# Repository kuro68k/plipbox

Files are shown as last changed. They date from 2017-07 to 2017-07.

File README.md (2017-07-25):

# plipbox

PCB for lallafa's plipbox (http://lallafa.de/blog/amiga-projects/plipbox/).

Allows an Amiga to connect to an ethernet network via the parallel port. Very low cost, uses an Arduino Nano V3 and ethernet shield.

This PCB is 2 layers. There is no cost advantage to single layer when ordering from Chinese manufacturers like Seeed Studio, and two layers means no need for jumper wires.

In addition there is a low cost TTL to RS232 level shifter. It's entirely optional, and if fitted allows the Amiga to configure the plipbox via connection to the serial port.

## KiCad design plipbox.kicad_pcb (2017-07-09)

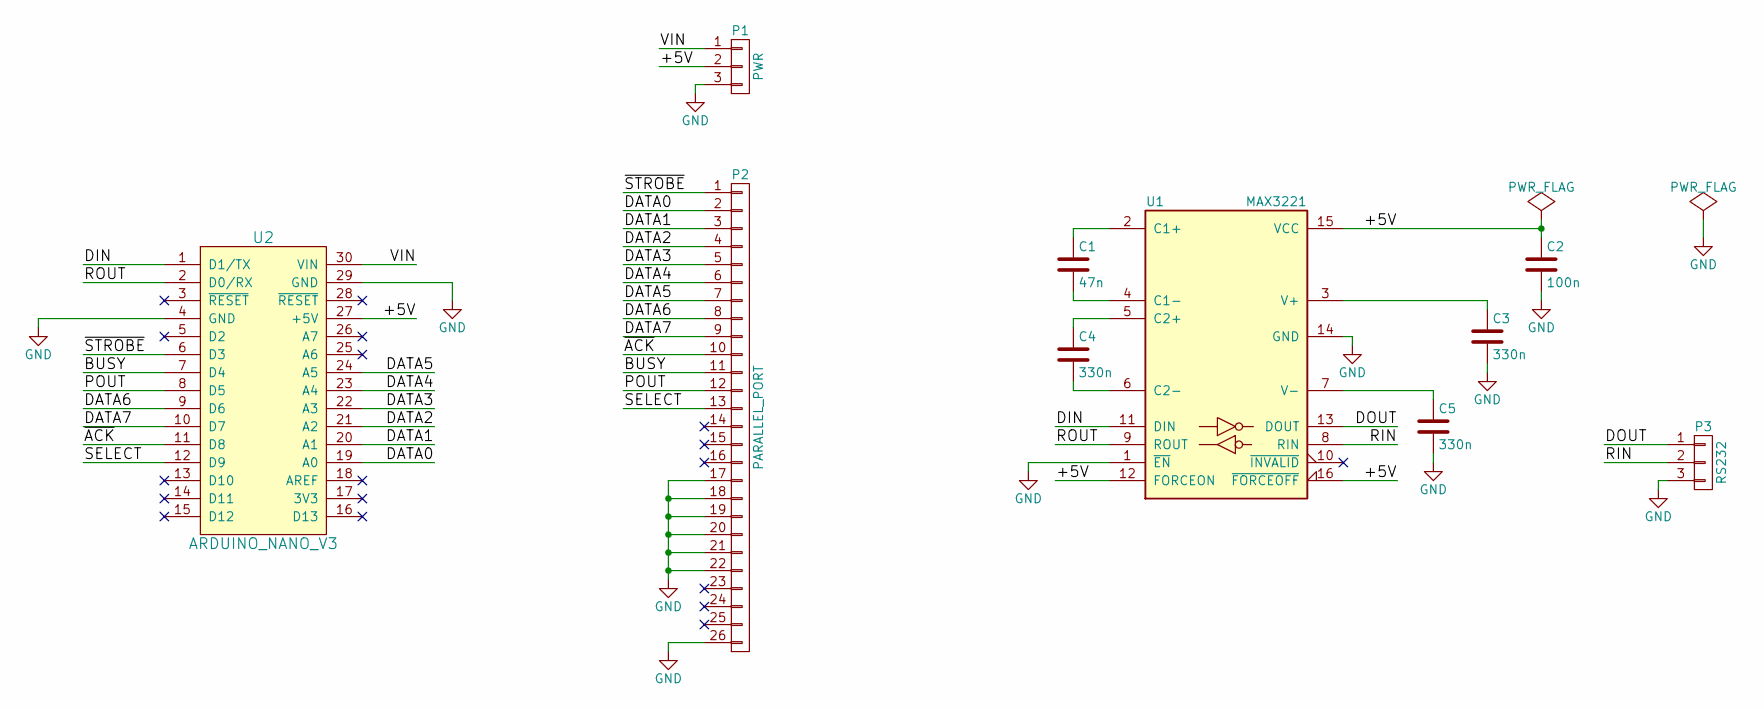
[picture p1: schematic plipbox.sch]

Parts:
C1: 47n; C_0603_HandSoldering
C2: 100n; C_0603_HandSoldering
C3, C4, C5: 330n; C_0603_HandSoldering
P1: PWR; Pin_Header_Straight_1x03_Pitch2.54mm
P2: PARALLEL_PORT; DB25M-RA-TH
P3: RS232; Pin_Header_Straight_1x03_Pitch2.54mm
U1: MAX3221; TSSOP-16_4.4x5mm_Pitch0.65mm
U2: ARDUINO_NANO_V3; DIP-30_W15.24mm_LongPads

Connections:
/+5V: C2.1, P1.2, U1.12 (FORCEON), U1.15 (VCC), U1.16 (~FORCEOFF), U2.27 (+5V)
/BUSY: P2.11, U2.7 (D4)
/DATA0: P2.2, U2.19 (A0)
/DATA1: P2.3, U2.20 (A1)
/DATA2: P2.4, U2.21 (A2)
/DATA3: P2.5, U2.22 (A3)
/DATA4: P2.6, U2.23 (A4)
/DATA5: P2.7, U2.24 (A5)
/DATA6: P2.8, U2.9 (D6)
/DATA7: P2.9, U2.10 (D7)
/DIN: U1.11 (DIN), U2.1 (D1/TX)
/DOUT: P3.1, U1.13 (DOUT)
/POUT: P2.12, U2.8 (D5)
/RIN: P3.2, U1.8 (RIN)
/ROUT: U1.9 (ROUT), U2.2 (D0/RX)
/SELECT: P2.13, U2.12 (D9)
/VIN: P1.1, U2.30 (VIN)
/~ACK: P2.10, U2.11 (D8)
/~STROBE: P2.1, U2.6 (D3)
GND: C2.2, C3.2, C5.2, P1.3, P2.17, P2.18, P2.19, P2.20, P2.21, P2.22, P2.26, P3.3, U1.1 (~EN), U1.14 (GND), U2.4 (GND), U2.29 (GND)
unnamed: C1.1, U1.2 (C1+)
unnamed: C1.2, U1.4 (C1-)
unnamed: C3.1, U1.3 (V+)
unnamed: C4.1, U1.5 (C2+)
unnamed: C4.2, U1.6 (C2-)
unnamed: C5.1, U1.7 (V-)

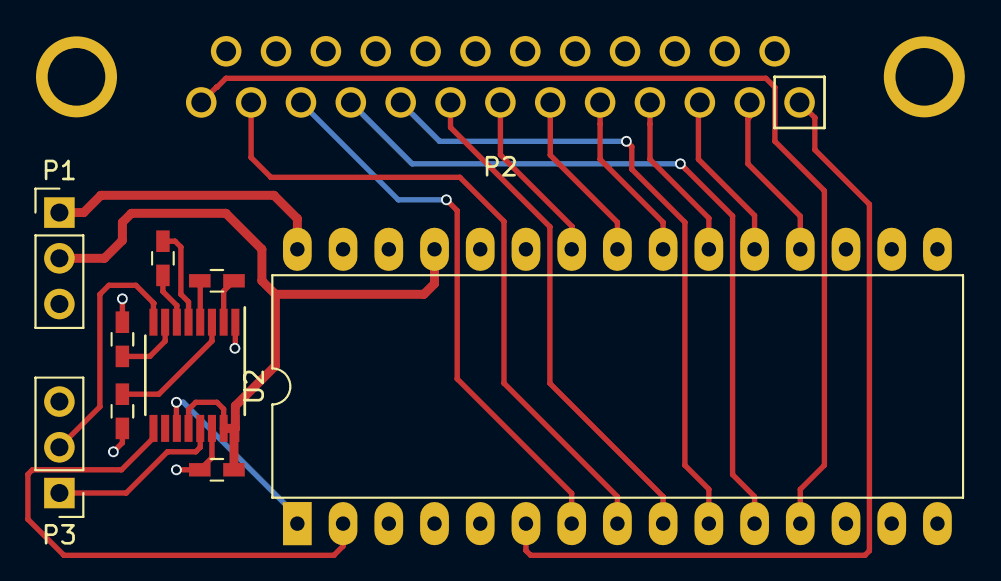
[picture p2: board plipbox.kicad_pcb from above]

Board: 2 copper layers, 10 parts (0 on the bottom side), 26 nets.

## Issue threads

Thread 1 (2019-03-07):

BOM / Parts list

soydemadrid, 2019-03-07:

sircompo, 2019-11-22:
Looking in the KiCad schematic (plipbox.sch), U1 appears to be a MAX3221 in a TSSOP-16 package.
https://www.ti.com/store/ti/en/p/product/?p=MAX3221IPWR

As for the caps, they're 0603 sized with the following values -
C1	47n
C2	100n
C3	330n
C4	330n
C5	330n

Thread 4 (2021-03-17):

RS232 Transceiver and Programming

appiah4, 2021-03-17:
Can you confirm the RS232 Transceiver BOM?  If U1 is indeed a MAX3221 (which is not easy to source) would SN35C3221EPWR work in its place?

Also, does the RS232 circuit connect directly to the Serial port?  What shell commands are needed to program it?  Can you add a bit more documentation.

kuro68k, 2021-03-17:
Is that part number right, Google comes up empty.

All documentation here: https://lallafa.de/blog/amiga-projects/plipbox/

appiah4, 2021-04-23:
Hi, I made a typo apparently, meant to ask about SN65C3321E PWR: https://cdn.ozdisan.com/ETicaret_Dosya/348021_4850776.pdf

Thanks for the link to the documentation.  I got a few boards printed and assembled one with the IC mentioned above.  Would it be safe to try?

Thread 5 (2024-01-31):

Hole sizes for DB25 and Nano different?

ByteMavericks, 2024-01-31:
Fitting the Nano Ethernet Shield in the drilled holes is very tight: is there any reason not to increase the size of the holes to 1.1mm to match the DB25 connector holes?

Happy to make the change, I just didn't want to break anything: any thoughts?

kuro68k, 2024-01-31:
It's so long since I worked on it, I don't remember. Probably used the part that came with KiCad.

Seems like a reasonable modification. Ideally you could get some boards made to check it. I know it's only a small change, but I don't want someone to send off for boards and find they have problems.

I guess you will have to upgrade the project to KiCad 7 as well. Please make sure it passes all the default DRC and ERC rules, and clearances are suitable for major Chinese board manufacturers like JLCPCB and PCB Way.

You are probably regretting offering now! I know it's a lot of work, but for public stuff it's worth the effort.

ByteMavericks, 2024-02-01:
Many thanks for replying!  I thought it'd be pulled in from a library. The pins do fit, but there's almost no tolerance on them and with the long pins on the Ethernet Nano shield it's a bit of a pain.

I've tried to upgrade to 7 and it seemed to pull things in correctly and pass the DRC and ERC...  Will check again, and I will send a test batch off to jlcpcb just to check.

Thanks again.

kuro68k, 2024-02-01:
Your welcome. I look forward to the pull request!

One thing I should have done is add a PDF schematic and a PNG of the gerbers, and maybe a JPEG of the manufactured board. I hate it when I find a board I have to download just to get a quick peak at to see if it's what I want, but I'm as guilty as any of not making the web compatible outputs.

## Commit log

2017-07-02 ERC power flag errors
    [plipbox.sch]
2017-07-02 Started PCB
    [plipbox.kicad_pcb]
2017-07-03 Board outline
    [plipbox.kicad_pcb]
2017-07-03 More compact U1
    [plipbox.kicad_pcb]
2017-07-03 Routed, DRC OK
    [plipbox.kicad_pcb]
2017-07-09 Fixed DB25M footprint
    [plipbox.kicad_pcb]
2017-07-09 Imperial drill file for Seeed
    [plipbox-Eco1.User.gto, plipbox-Eco2.User.gbo, plipbox.drl]
